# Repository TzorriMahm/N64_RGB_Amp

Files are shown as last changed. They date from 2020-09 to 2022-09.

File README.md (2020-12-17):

# N64 RGB Amp
**A modding board to achieve RGB video on some early NTSC models by using TI's THS7374 video amplifier.**<br>

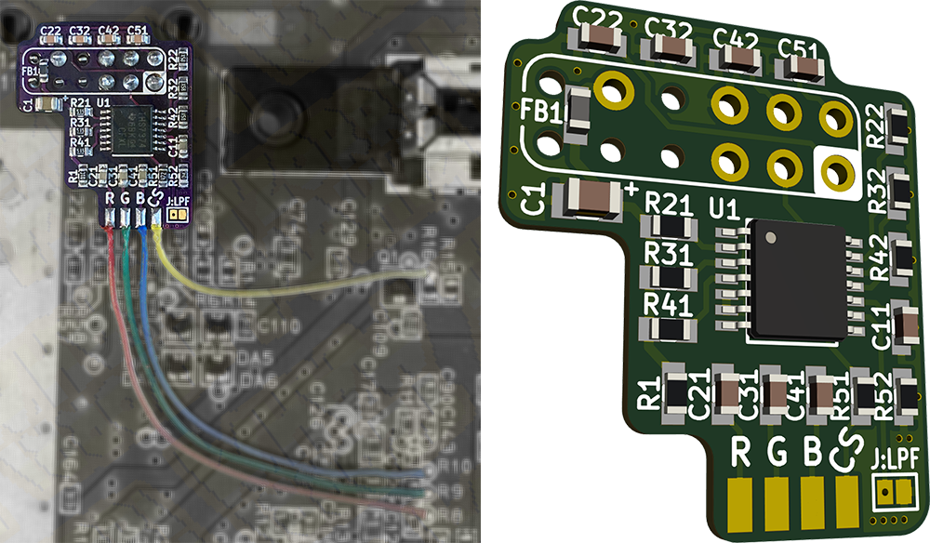
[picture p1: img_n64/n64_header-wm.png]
Header image

<br><br>
**⁓ Designed with ♥ in Germany ⁓**<br><br>
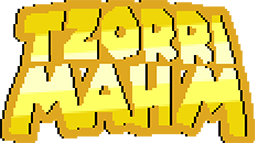
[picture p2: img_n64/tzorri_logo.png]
TzorriMahm

# Where to get the PCB?
You can order the PCB directly from [OSHPark](https://oshpark.com/shared_projects/cdlxvTEA).
Of course, feel free to use the gerber files with any manufacturer of your choice.<br>
Use 0.8mm board thickness to ensure an easy and clean installation.

# Before you start
**This modification only works with NUS-CPU-01/02/03/04 main board revisions!**<br>
Also, verify that your main board has a 'VDC-NUS'/'VDC-NUS A' chip (U4).<br>
If that's not the case - **stop here!** Your console is not compatible with this modding board!

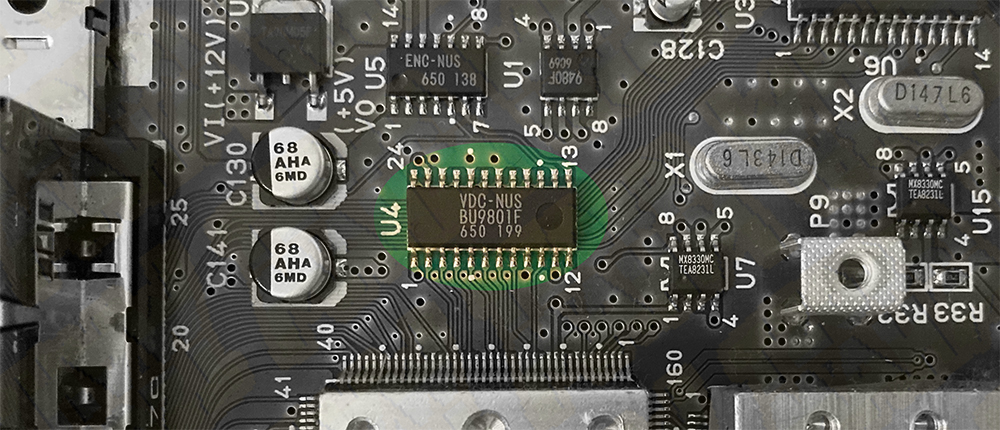
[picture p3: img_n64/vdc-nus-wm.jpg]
VDC-NUS


# Install instructions
## Bottom metal shielding
Use a pair of pliers to bend away the tab which is located at the MultiOut area.<br>
This avoids the shielding from hitting the modding board later.

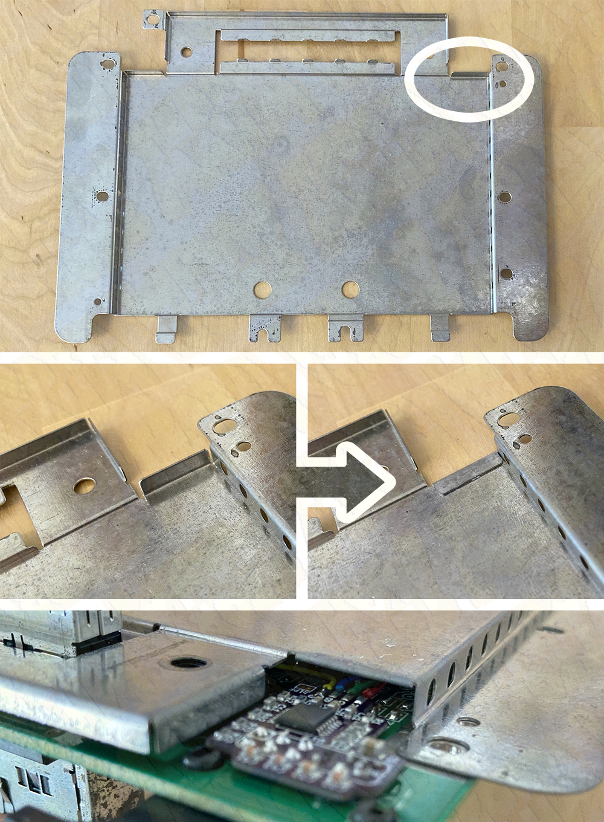
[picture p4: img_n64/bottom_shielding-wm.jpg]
Bottom metal shielding
<br>

## Preparing the N64 main board
- remove R1, R14, R15, R16, C22

## Installing the modding board
- isolate the bottom side of the modding board to avoid any shorts
- solder the modding board onto the pins of the MultiOut
- solder a wire from the via next to R8 (N64 main board) to pad 'R' (modding board)
- solder a wire from the via next to R9 (N64 main board) to pad 'G' (modding board)
- solder a wire from the via next to R10 (N64 main board) to pad 'B' (modding board)
- solder a wire from the via next to R16 (N64 main board) to pad 'CS' (modding board)<br>

## Install diagram
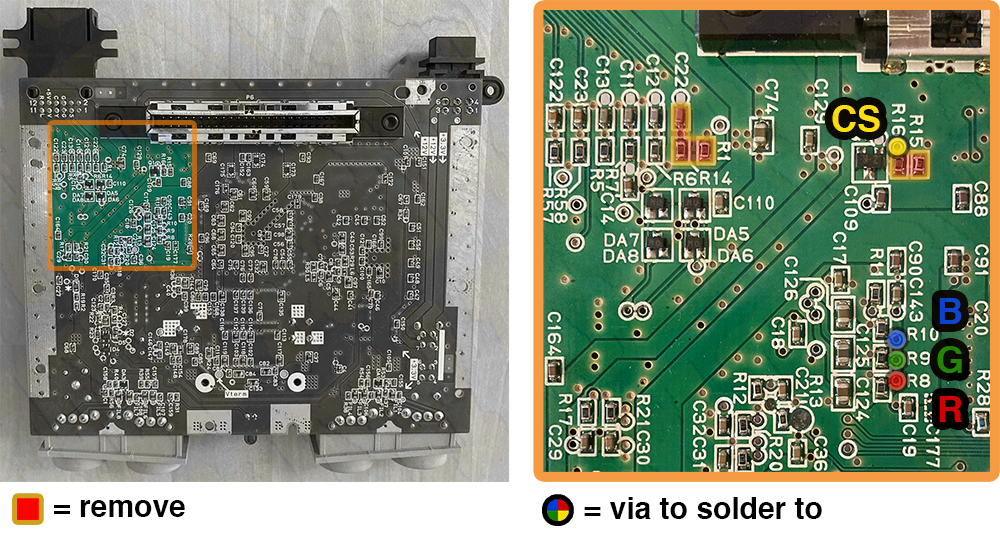
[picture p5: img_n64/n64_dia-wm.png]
Install diagram


# Troubleshooting
Double-check continuity between connections:
- 'R' (modding board) ⇄ VDC-NUS(A) pin 17 (N64 main board)
- 'G' (modding board) ⇄ VDC-NUS(A) pin 19 (N64 main board)
- 'B' (modding board) ⇄ VDC-NUS(A) pin 21 (N64 main board)
- 'CS' (modding board) ⇄ VDC-NUS(A) pin 14 (N64 main board)

**Check for shorts to VDC-NUS(A)!** The vias you solder to are located directly beneath that IC.<br>
It's ridiculously-simple to short something when the exposed conductors are a little bit too long!

# Miscellaneous
#### Jumper 'J:LPF'
The THS7374 has a low pass filter on each of the four channels which can be turned on by shorting jumper 'J:LPF' on the modding board. This is mostly needed if you wire the console directly to a flat-screen TV. There's no need for the low pass filter on analogue devices.<br>
If you use an OSSC or a Framemeister, it's better to use their filter options.

#### RGB cable
You will need a RGB cable with 220µF electrolytic capacitors on each of the 'R', 'G' & 'B' lines. The positive end is facing towards the console.<br>
This modding board is designed to output TTL level C-Sync directly at the MultiOut of the console.<br>
With that in mind, make sure you're using a suitable cable with a 470Ω resistor on the sync line to use it with most consumer products (like TV's, OSSC, Framemeister)!

# Disclaimer
I am not responsible for any damage to you, your devices or anything else!<br>
If you do the modification, you do it at your own risk and responsibility!

# Acknowledgement
Most of the credits should go to [borti4938](https://github.com/borti4938). He has made the actual (slightly different) circuit and inspired me to design this board. Thanks man! Thanks Bob, for your awesome and informative website [RetroRGB](http://retrorgb.com)!<br>
And of course, thanks to the whole retro gaming community for keeping the spirit alive!

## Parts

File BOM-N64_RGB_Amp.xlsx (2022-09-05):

N64 RGB Amp - Bill of Materials
Designator | Mfr. No | Quantity | Description | Package | Value | Mouser
U1 | THS7374IPWR | 1 | 4-Ch. SD Video Amp | TSSOP-14 |  | https://www.mouser.de/ProductDetail/Texas-Instruments/THS7374IPWR?qs=qU0TI%2FZyA%252BxCw%252BZ%2FnXjpBw%3D%3D
C1 | 08053D226MAT2A | 1 | Ceramic capacitor; X5R; 25V | SMD0805 | 22µF / 20% | https://www.mouser.de/ProductDetail/AVX/08053D226MAT2A?qs=bxXxiBiblXqtZp79ClJbtg%3D%3D
C11 | 06035C104KAT2A | 1 | Ceramic capacitor; X7R; 50V | SMD0603 | 100nF / 10% | https://www.mouser.de/ProductDetail/AVX/06035C104KAT2A?qs=wORnlwVG%2F0dQ8Y%2FnMEnCGg%3D%3D
C21, C31, C41 | 0603YC823KAT2A | 3 | Ceramic capacitor; X7R; 16V | SMD0603 | 82nF / 10% | https://www.mouser.de/ProductDetail/AVX/0603YC823KAT2A?qs=Gc704lYbI0w4J5zALMwFzw%3D%3D
C22, C32, C42, C51 | 0603YC470KAT2A | 4 | Ceramic capacitor; X7R, 16V | SMD0603 | 47pF / 10% | https://www.mouser.de/ProductDetail/AVX/0603YC470KAT2A?qs=EU6FO9ffTwcFkDrBSOUNAw%3D%3D
FB1 | MPZ1608S221ATA00 | 1 | Ferrite bead; power line | SMD0603 |  | https://www.mouser.de/ProductDetail/TDK/MPZ1608S221ATA00
R1 | RC0603FR-0710KL | 1 | Resistor; 1/10W | SMD0603 | 10kΩ / 1% | https://www.mouser.de/ProductDetail/Yageo/RC0603FR-0710KL?qs=grNVn54RoB%252B3GtjbJj3wJQ%3D%3D
R21, R31, R41 | RC0603FR-075M1L | 3 | Resistor; 1/10W | SMD0603 | 5.1MΩ / 1% | https://www.mouser.de/ProductDetail/Yageo/RC0603FR-075M1L
R22, R32, R42 | RC0603FR-0775RL | 3 | Resistor; 1/10W | SMD0603 | 75Ω / 1% | https://www.mouser.de/ProductDetail/Yageo/RC0603FR-0775RL
R51 | RC0603FR-074K7L | 1 | Resistor; 1/10W | SMD0603 | 4.7kΩ / 1% | https://www.mouser.de/ProductDetail/Yageo/RC0603FR-074K7L
R52 | RC0603FR-0710K7L | 1 | Resistor; 1/10W | SMD0603 | 10.7kΩ / 1% | https://www.mouser.de/ProductDetail/Yageo/RC0603FR-0710K7L
Mouser Basket: | https://www.mouser.de/ProjectManager/ProjectDetail.aspx?AccessID=139e1f6c21

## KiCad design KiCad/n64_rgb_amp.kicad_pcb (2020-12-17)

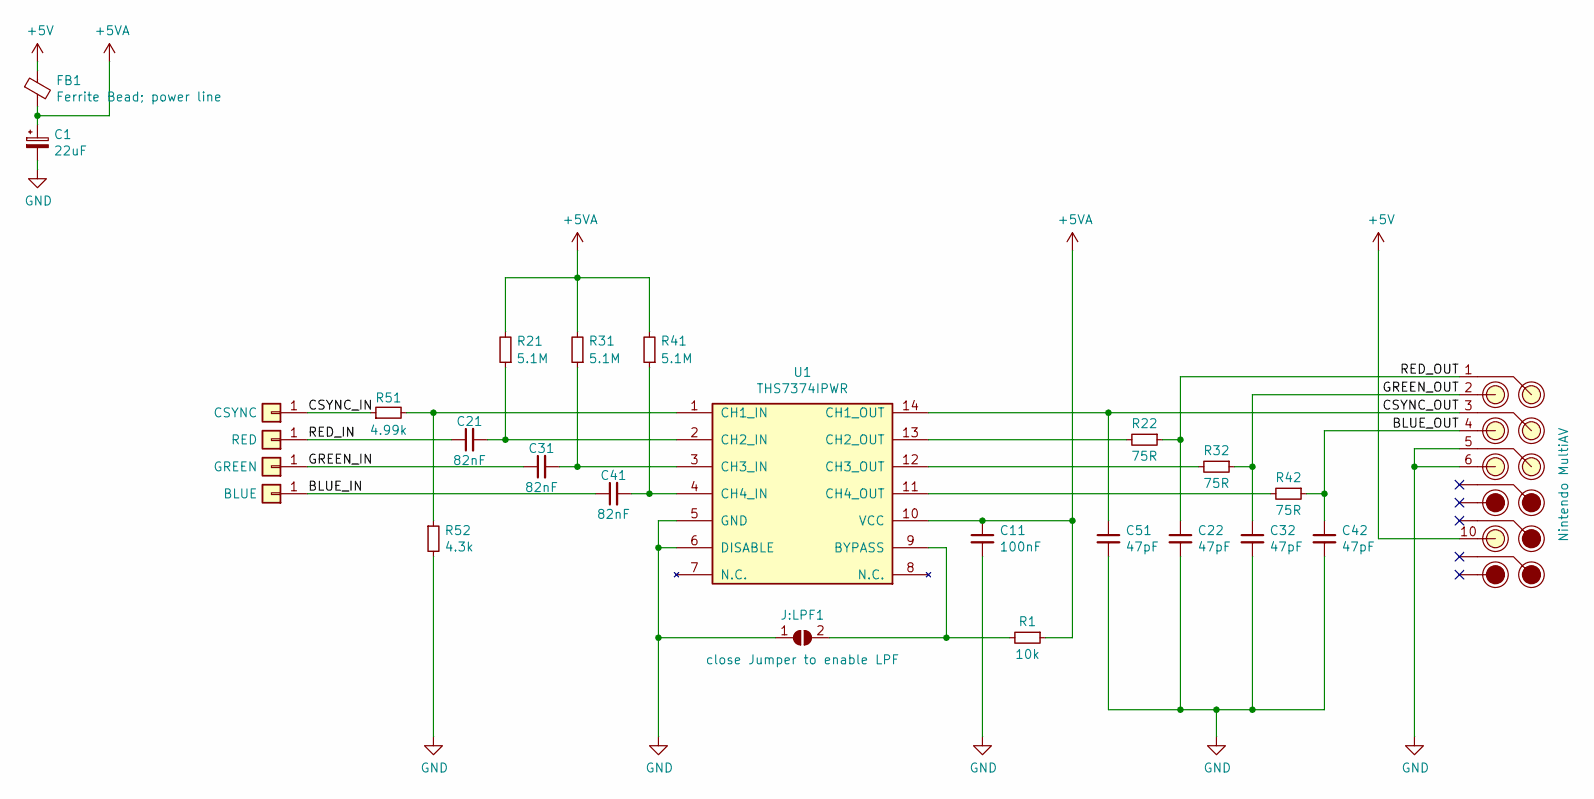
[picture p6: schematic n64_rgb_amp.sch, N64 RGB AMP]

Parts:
C1: 22uF; C_SMD0805
C11: 100nF; C_SMD0603
C21, C31, C41: 82nF; C_SMD0603
C22, C32, C42, C51: 47pF; C_SMD0603
FB1: Ferrite Bead; power line; FB_SMD0603
INPUT_1: RED; SolderPad_customizable
INPUT_2: GREEN; SolderPad_customizable
INPUT_3: BLUE; SolderPad_customizable
INPUT_4: CSYNC; SolderPad_customizable
J:LPF1: close Jumper to enable LPF; SolderJumper_2x0.75x1mm
MultiAV1: Nintendo MultiAV; NintendoMultiAV_FB-gap
R1: 10k; R_SMD0603
R21, R31, R41: 5.1M; R_SMD0603
R22, R32, R42: 75R; R_SMD0603
R51: 4.99k; R_SMD0603
R52: 4.3k; R_SMD0603
U1: THS7374IPWR; TSSOP-14

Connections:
+5V: FB1.1, MultiAV1.10
+5VA: C1.1, C11.1, FB1.2, R1.1, R21.2, R31.2, R41.2, U1.10 (VCC)
/BLUE_IN: C41.1, INPUT_3.1
/BLUE_OUT: C42.1, MultiAV1.4, R42.1
/CSYNC_IN: INPUT_4.1, R51.1
/CSYNC_OUT: C51.1, MultiAV1.3, U1.14 (CH1_OUT)
/GREEN_IN: C31.1, INPUT_2.1
/GREEN_OUT: C32.1, MultiAV1.2, R32.1
/RED_IN: C21.1, INPUT_1.1
/RED_OUT: C22.1, MultiAV1.1, R22.1
GND: C1.2, C11.2, C22.2, C32.2, C42.2, C51.2, J:LPF1.1 (A), MultiAV1.5, MultiAV1.6, R52.2, U1.5 (GND), U1.6 (DISABLE)
unnamed: C21.2, R21.1, U1.2 (CH2_IN)
unnamed: C31.2, R31.1, U1.3 (CH3_IN)
unnamed: C41.2, R41.1, U1.4 (CH4_IN)
unnamed: J:LPF1.2 (B), R1.2, U1.9 (BYPASS)
unnamed: R22.2, U1.13 (CH2_OUT)
unnamed: R32.2, U1.12 (CH3_OUT)
unnamed: R42.2, U1.11 (CH4_OUT)
unnamed: R51.2, R52.1, U1.1 (CH1_IN)

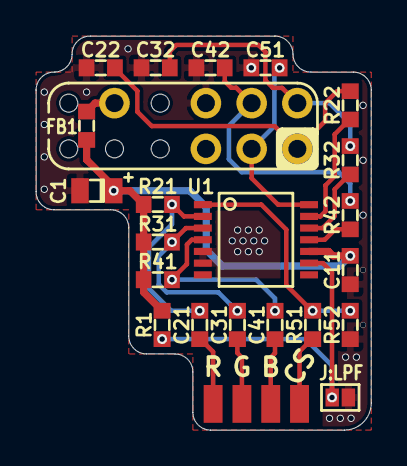
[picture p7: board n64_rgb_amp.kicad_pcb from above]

Board: 2 copper layers, 18.6 x 21.9 mm, 27 parts (1 on the bottom side), 19 nets.

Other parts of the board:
***: TM_logo-silk

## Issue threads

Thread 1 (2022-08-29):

Incorrect cap position number in BOM

hitmanmcc, 2022-08-29:
In the BOM cap C31 is mentioned twice, one of those mentions should be C41.
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
I tried to submit a PR with the update but I do not have access rights.

TzorriMahm, 2022-09-05:
Fixed. Thank you! :)

hitmanmcc, 2022-09-05:
My pleasure! :)

Closed 2022-09-05.

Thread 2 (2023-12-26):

a lot of diagonal stripes moved

Cyrus331, 2023-12-26:
After I installed this module, when I used GBSC to display, a lot of diagonal stripes moved. The same happened when I added a 470R resistor to C-Sync. Has anyone encountered this situation? How to solve it?

TzorriMahm, 2023-12-27:
Frankly, I never encountered such behavior in like 30+ installs.

Some questions:
- correct revision?
- double-checked install?
  - maybe short to ground?
- cable works properly with other consoles?
- I'm not into GBS-C, but is the Resistor between sync and ground present?
- did you buy or assembled the modding board?

Cyrus331, 2023-12-27:
Thanks for the reply. I solved the problem unintentionally. Maybe the problem really lies with GBS-C, because I saw the resolution conversion knob on GBS-C and turned it to 720P. Miraculously, the twill lines were gone.

Closed 2023-12-27.

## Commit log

2020-12-17 Add KiCad design files; update to v3.2
    - add KiCad design files
    - update to v3.2; minor changes - nothing special
    [n64_rgb_amp.kicad_pcb, n64_rgb_amp.sch]
2020-12-17 Add KiCad design files; update to v1.1
    - update to v1.1; minor changes - nothing special
    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
2020-12-17 Revert "Add KiCad design files; update to v3.2"
    This reverts commit 25f73cbb464701b12caae3678c85ef64555b3520.
    [n64_rgb_amp.kicad_pcb, n64_rgb_amp.sch]
2020-12-17 Add KiCad files for v1.1
    - project file
    - schematics
    - design
    - libraries
    - footprints
    [n64_rgb_amp.kicad_pcb, n64_rgb_amp.sch]
2020-12-17 Replace gerber files to match v1.1
    [N64 RGB AMP v1-B_Mask.gbs, N64 RGB AMP v1-B_SilkS.gbo, N64 RGB AMP v1-Component.gtl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]
2022-09-05 Fixed typo in BOM. Thanks, @hitmanmcc!
    [BOM-N64_RGB_Amp.xlsx]
